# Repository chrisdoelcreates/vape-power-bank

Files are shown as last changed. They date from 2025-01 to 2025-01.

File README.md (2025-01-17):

# Disposable Vape Powerbank Project

This repository contains everything you need to build a functional 100W power bank using lithium-ion cells salvaged from disposable vapes.

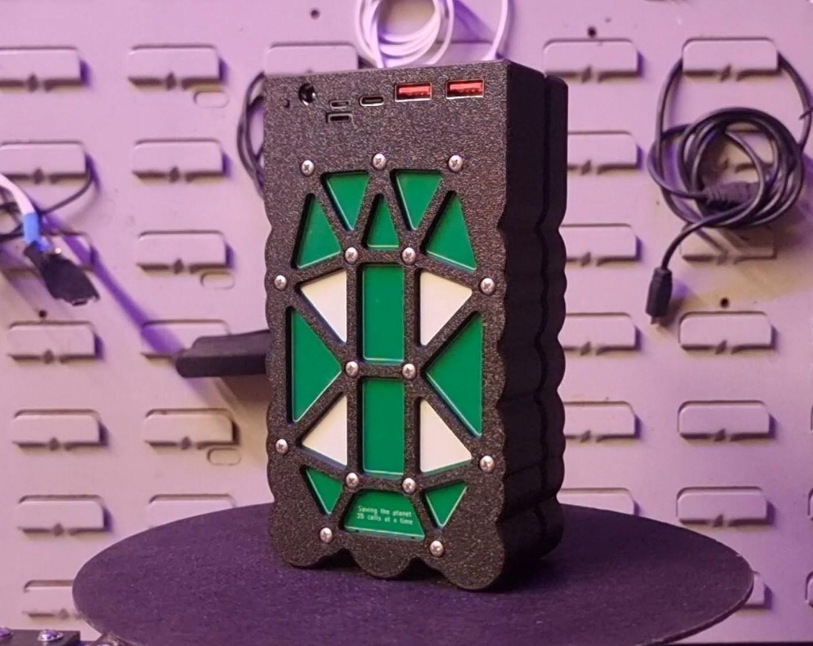
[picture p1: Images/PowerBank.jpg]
Finished Power Bank


## 📺 Watch the Video

See the entire build process in action on my YouTube channel:

[Watch on YouTube](https://youtu.be/kMiJdfgIfqI)

---

This powerbank is an upgrade from my [initial design](https://www.youtube.com/watch?v=ehp23hrrEHY) and is now smaller, lighter, safer, and easier to assemble.
It’s a fantastic way to repurpose vape batteries and contribute to reducing e-waste while learning valuable electronics and 3D printing skills.

---

## ⚠️ Disclaimer

This project involves handling lithium-ion batteries, which can be dangerous if mishandled. By using these designs or instructions, you acknowledge and agree to the following:

- You assume all risks associated with the assembly and use of this project.
- This project is provided "as-is," with no guarantees of safety or performance.
- Always take appropriate safety precautions and seek professional guidance if unsure.

Please read the full [Disclaimer](DISCLAIMER.md) before proceeding.

---

## Affiliate Links & Sponsorship Disclosure

This repository contains affiliate links to suppliers and services. If you use these links to purchase parts (from Aliexpress) or sign up for services (such as JLCPCB), I may earn a small commission at no extra cost to you. These links help support the development of this project and my YouTube channel.

Thank you for supporting my work!

---

## 🚀 Project Overview

In this project, you will:
- Extract lithium-ion cells from disposable vapes.
- Test and prepare the cells for use.
- Assemble a 3D-printed cell holder and enclosure.
- Install custom PCBs to balance charge the cells and wire them up to form a 5S7P (5 cells in series, 7 cells in parallel) battery pack.
- Wire up a fast-charge USB powerbank board.

### Key Features:
- Doesn't require directly soldering the cells together.
- Multifunction PCBs (balance charging and power delivery) to reduce parts cost.
- Open-source PCBs & 3D prints for easy customization and collaboration.
- Supports 100W USB C PD charging.
---

## 📂 Repository Contents

This repository is organized as follows:
```
Disposable-Vape-Powerbank/
├── README.md           # Introduction and instructions
├── DISCLAIMER.md       # Full project disclaimer
├── LICENSE             # Project licensing details
├── PCB-Files/          # PCB related files
│   ├── Production-Files/   # PCB files for ordering
│   ├── Schematic.pdf       # PCB schematic
│   └── KiCad_Project/      # KiCAD project files
├── 3D-Models/          # Fusion360 files and links to printables
└── Images/             # Photos and renders of the project
```
## 🛠️ Quick Start Guide

Follow these steps to build your own disposable vape power bank:

1. *Download Files*
   - Click the green *Code* button and select *Download ZIP*. Then extract the repository files.
   - or clone the repository:
     git clone [https://github.com/username/Disposable-Vape-Powerbank.git](https://github.com/chrisdoelcreates/vape-power-bank)
     
2. *Order the PCBs*
    - Head over to [JLCPCB](https://jlcpcb.com/?from=cdd) (or any other PCB ordering site)
    - Sign up/Log in
    - Head to the order page
    - Upload the Gerber file from Disposable-Vape-Powerbank/PCB-Files/Production-Files/
    - Refer to 10:13 in the [project video](https://youtu.be/h3FRk3OD1Ug) for order settings
    - Ensure 'Assembly' is checked
    - Upload the CPL and BOM files
    - Rotate the connectors to match the orientation within the video
    - Place the order!
  *If you get an email asking if the polarities of the springs are correct - reply that they are*

3. *Order the USB board*
    - [USB board - Type 1 (Recommended - Used in the video)](https://s.click.aliexpress.com/e/_oBGOqhR)
       - *ENSURE THE 5S OPTION IS SELECTED*
    - [USB board - Type 2 (More USB C ports - requires different 3D prints to the video)](https://s.click.aliexpress.com/e/_oBXyxIH)
       - *ENSURE THE 5S OPTION IS SELECTED*

4. *Order the conductive tape*
    - [Conductive tape](https://s.click.aliexpress.com/e/_olaCL05)
       - *ENSURE the '10mm' & 'Conductive on both sides' options are selected*

5. *Order optional extras*
    - [Right angle JST connector](https://s.click.aliexpress.com/e/_oEeP6lf)
      - *ENSURE XH2.54MM, Length 10CM, 4P IS SELECTED*
      - Not essential but makes wiring the board slightly easier
    - [8 Channel Cell Tester](https://s.click.aliexpress.com/e/_oEuMn9T)
      - Also not essential
      - Allows you to match the battery capacities for each parallel row - improves powerbank battery life & lifespan
      - Good if you regularly do battery related projects

6. *Print the parts*
    - Easiest: Find the right size on [printables](https://www.printables.com/@montecha_2397581/collections/2035794)
      Or
    - Download the cell holder from the 3D models folder
    - Download the enclosure from the 3D models folder
      - Select the enclosure depending on your board type
    - Print out the parts!

7. *Build the Powerbank!*
     - Follow along with the Youtube video

---

## 🧾 Licensing

This project is licensed under the [MIT License](LICENSE). You are free to use, modify, and distribute the files, provided you include proper attribution and accept the project’s disclaimers.

---

## 🤝 Contributions

Contributions are welcome! If you have suggestions, improvements, or issues, feel free to:
- Open an issue in this repository.
- Submit a pull request with your changes.

---

## 🌟 Acknowledgments

A big thank you to:
- *JLCPCB* for sponsoring the youtube video/project.
- Everyone who has supported and engaged with my Youtube channel.

---

Enjoy building your power bank and contributing to e-waste reduction!

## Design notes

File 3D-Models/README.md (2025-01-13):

# 3D Model Files

This directory contains 3D model files to print the enclosures and cell holders for the disposable vape power bank project. The models are organized by USB board type and compatible cell lengths to make it easy to find the appropriate files for your build.

If your cells are not 30mm, 35mm or 40mm in length, you can modify the cell holder and enclosure .step models to fit your particular cell size.

**NOTE:** This project only supports vape cells of 13mm diameter. 

## Overview
The project supports **two USB board types** and **three common cell lengths**:

### USB Board Types
1. [**Type 1 (Recommended)**](https://s.click.aliexpress.com/e/_oBGOqhR)
   - This is the primary USB board featured in the project video.
   - It is recommended for most users.
2. [**Type 2**](https://s.click.aliexpress.com/e/_oBXyxIH)
   - Features a larger screen and more USB ports.
   - Requires slightly different 3D printed parts due to the board's size and layout.

### Cell Lengths
The models are optimized for the following common cell lengths:
- **30mm cells**: Typically referred to as 13300 cells.
- **35mm cells**: Typically referred to as 13350 cells.
- **40mm cells**: Typically referred to as 13400 cells.

Each folder contains the necessary 3D models to build the enclosure and cell holder for the specified cell length.

---

## Directory Structure

The file structure is organized as follows:

```
├───USB Board Type 1
│   ├───30mm_cell
│   │   ├───Step
│   │   └───STL
│   ├───35mm_cell
│   │   ├───Step
│   │   └───STL
│   └───40mm_cell
│       ├───Step
│       └───STL
└───USB Board Type 2
    ├───30mm_cell
    │   ├───Step
    │   └───STL
    ├───35mm_cell
    │   ├───Step
    │   └───STL
    └───40mm_cell
        ├───Step
        └───STL
```

### Folders and File Types
- **Step Folder**: Contains `.step` files for the parts required for each different cell type, which can be used in CAD software for further modifications.
- **STL Folder**: Contains `.3mf` files optimized for 3D printing.
  - Includes parts like:
    - `cell_holder`
    - `enclosure_bottom`
    - `enclosure_top`
    - (for Type 2) `enclosure_top_tab`

---

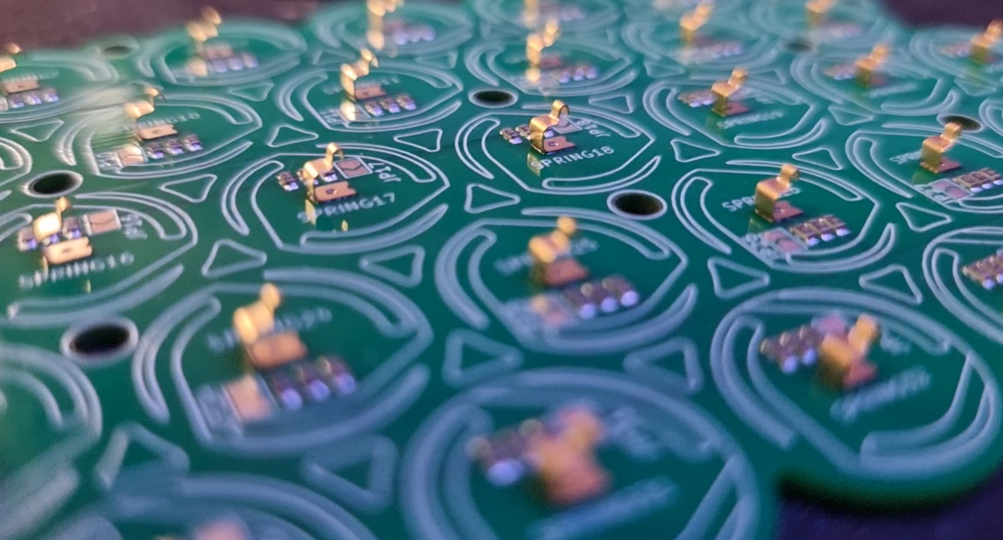
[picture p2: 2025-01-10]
Images/PCB_close_up.jpg

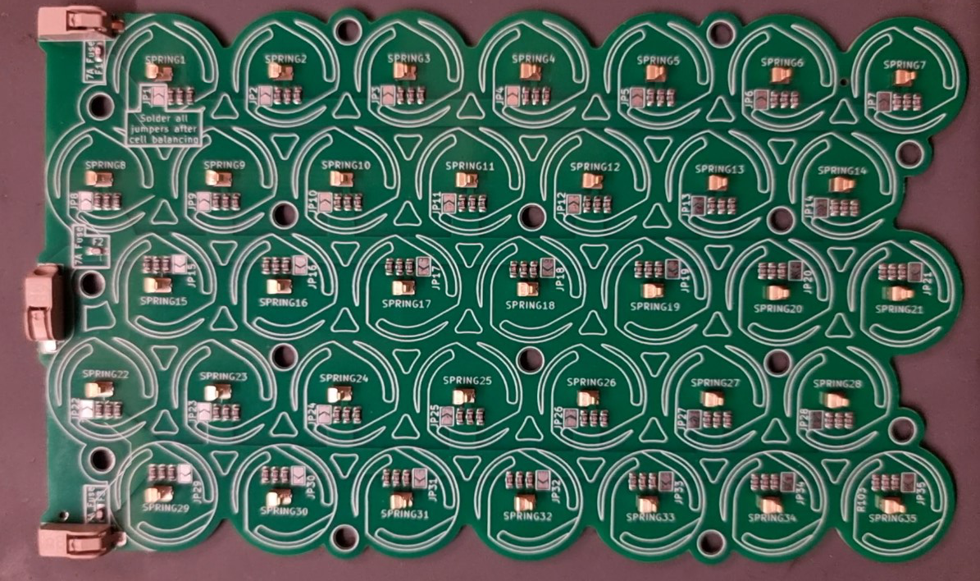
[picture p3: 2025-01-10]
Images/PCB.jpg

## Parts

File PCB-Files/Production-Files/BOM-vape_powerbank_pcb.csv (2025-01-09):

Comment | Designator | Footprint | LCSC
R | R1,R10,R100,R101,R102,R103,R104,R105,R11,R12,R13,R14,R15,R16,R17,R18,R19,R2,R20,R21,R22,R23,R24,R25,R26,R27,R28,R29,R3,R30,R31,R32,R33,R34,R35,R36,R37,R38,R39,R4,R40,R41,R42,R43,R44,R45,R46,R47,R48,R49,R5,R50,R51,R52,R53,R54,R55,R56,R57,R58,R59,R6,R60,R61,R62,R63,R64,R65,R66,R67,R68,R69,R7,R70,R71,R72,R73,R74,R75,R76,R77,R78,R79,R8,R80,R81,R82,R83,R84,R85,R86,R87,R88,R89,R9,R90,R91,R92,R93,R94,R95,R96,R97,R98,R99 | R_0603_1608Metric | C23164
spring_tab | SPRING1,SPRING10,SPRING11,SPRING12,SPRING13,SPRING14,SPRING15,SPRING16,SPRING17,SPRING18,SPRING19,SPRING2,SPRING20,SPRING21,SPRING22,SPRING23,SPRING24,SPRING25,SPRING26,SPRING27,SPRING28,SPRING29,SPRING3,SPRING30,SPRING31,SPRING32,SPRING33,SPRING34,SPRING35,SPRING4,SPRING5,SPRING6,SPRING7,SPRING8,SPRING9 | spring_tab | C2826543
Fuse | F1,F2,F3 | Fuse_0603_1608Metric_Pad1.05x0.95mm_HandSolder | C310953
Conn_01x01_Pin | J1,J2,J3 | SMD_spring_clamp_connector_1x1 | C5197183

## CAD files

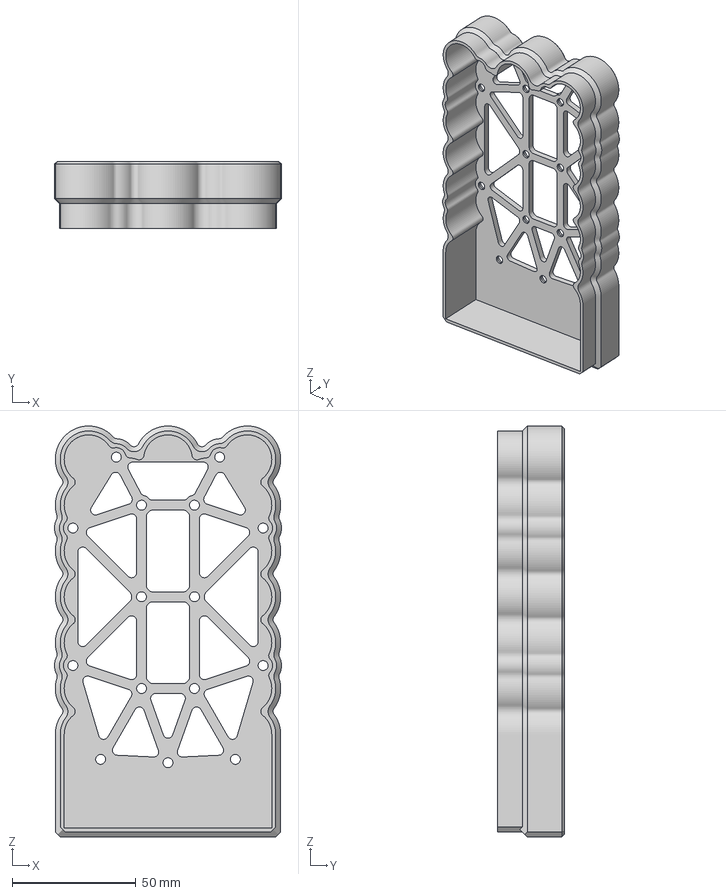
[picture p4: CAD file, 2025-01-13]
3D-Models/USB Board Type 1/30mm_cell/STL/Mk4 PCB 1 N&B 31mm Base Protector.3mf
91.6 x 27.0 x 165.9 mm

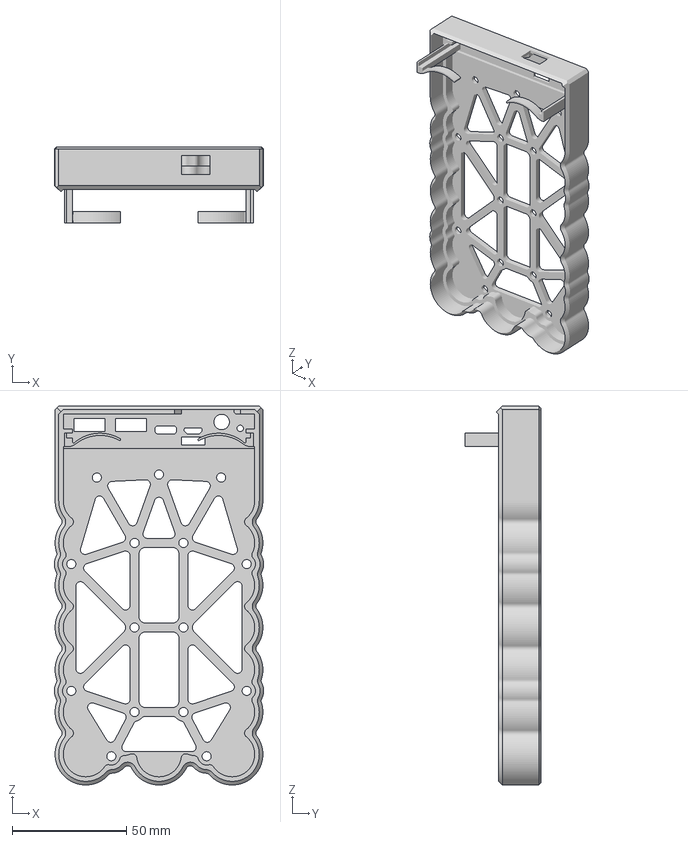
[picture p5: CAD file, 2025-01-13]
3D-Models/USB Board Type 1/35mm_cell/STL/Mk4 PCB 1 N&B 36mm Top Protector.3mf
91.6 x 33.4 x 165.9 mm

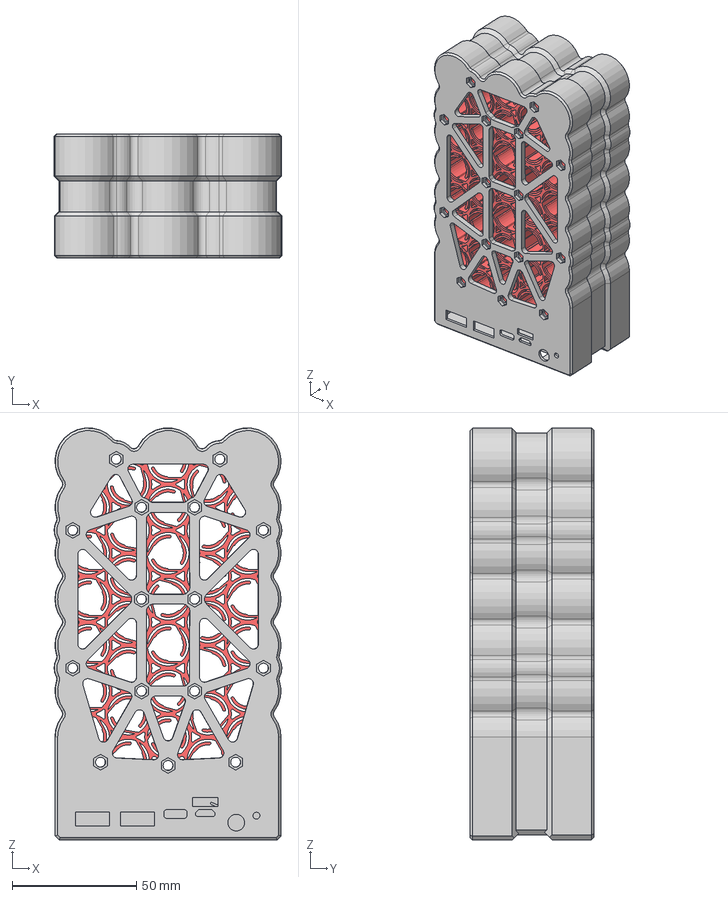
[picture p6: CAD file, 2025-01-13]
3D-Models/USB Board Type 1/40mm_cell/Step/40mm_cell_prints.step
91.8 x 50.0 x 165.9 mm
Base protector
Top protector
41mm cell holder

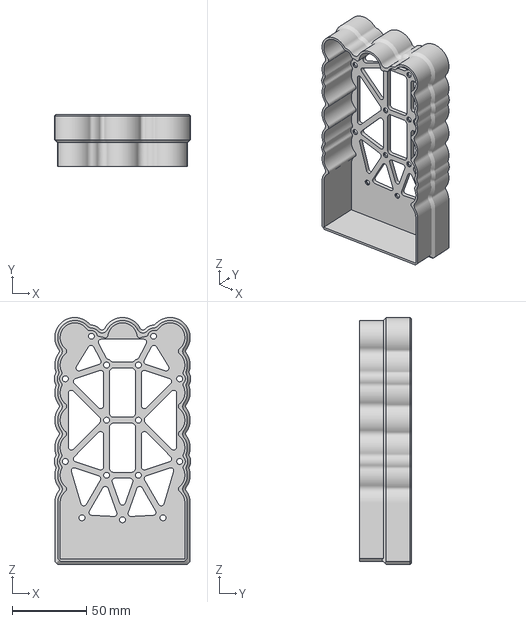
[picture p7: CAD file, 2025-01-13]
3D-Models/USB Board Type 1/40mm_cell/STL/enclosure_bottom.3mf
91.6 x 35.0 x 165.9 mm

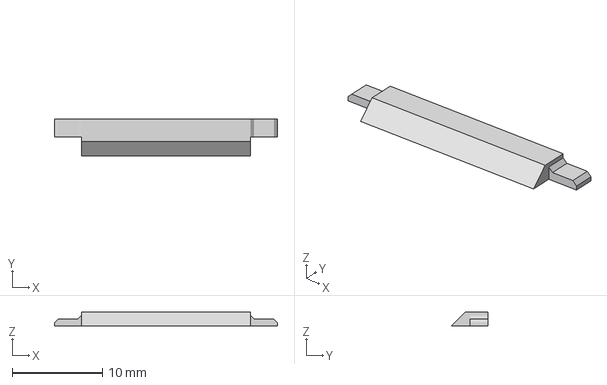
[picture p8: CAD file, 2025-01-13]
3D-Models/USB Board Type 2/30mm_cell/STL/enclosure_top_tab.3mf
24.7 x 4.10 x 1.60 mm

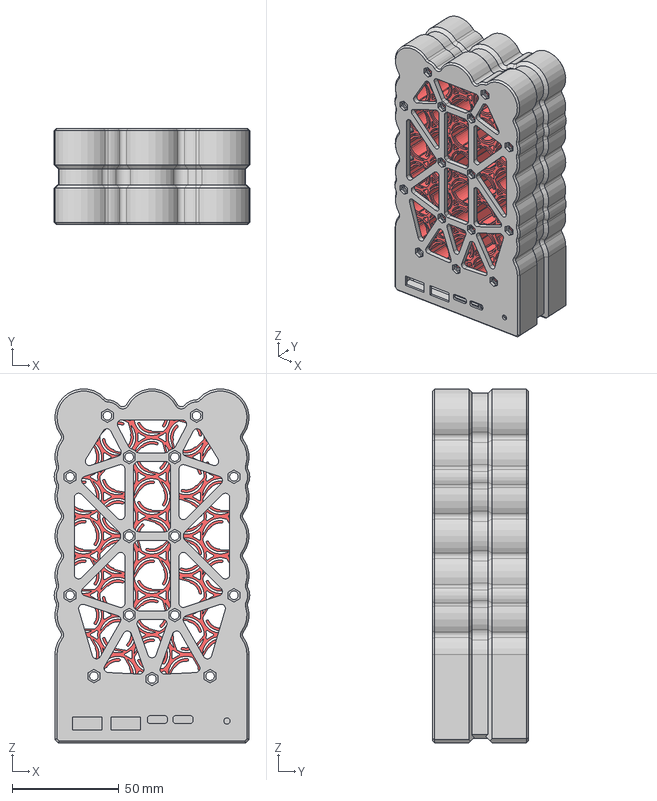
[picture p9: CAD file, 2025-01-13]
3D-Models/USB Board Type 2/35mm_cell/Step/35mm_cell_prints.step
91.6 x 45.0 x 165.8 mm
Base protector
Top protector
Cell Holder Mk2

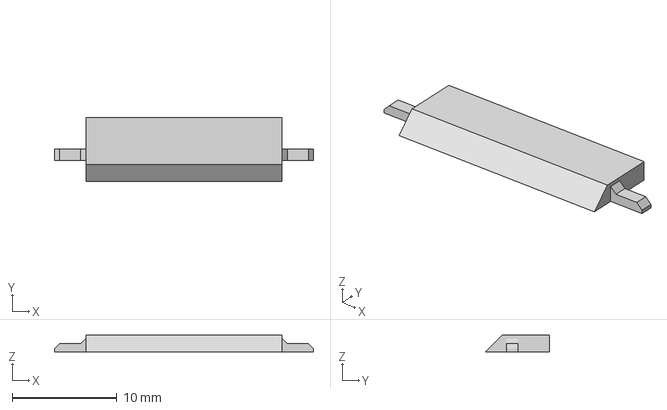
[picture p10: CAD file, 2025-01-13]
3D-Models/USB Board Type 2/40mm_cell/STL/enclosure_top_tab.3mf
24.7 x 6.10 x 1.60 mm

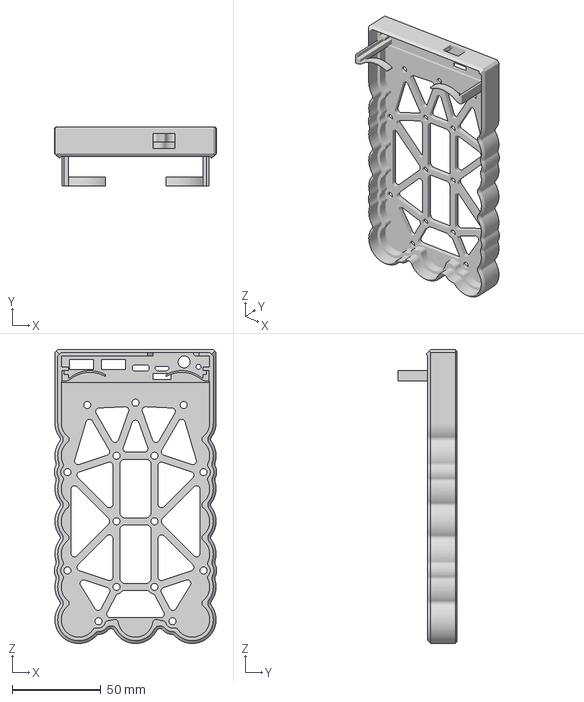
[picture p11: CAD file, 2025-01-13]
3D-Models/USB Board Type 1/30mm_cell/STL/Mk4 PCB 1 N&B 31mm Top Protector .3mf
91.6 x 33.4 x 165.9 mm

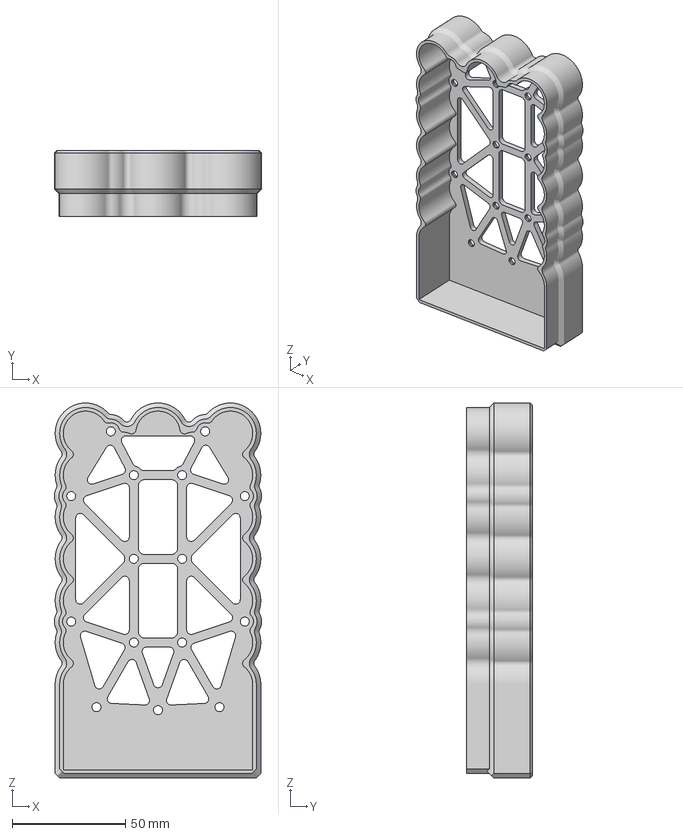
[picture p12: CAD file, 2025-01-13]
3D-Models/USB Board Type 1/35mm_cell/STL/Mk4 PCB 1 N&B 36mm Base Protector.3mf
91.6 x 29.0 x 165.9 mm

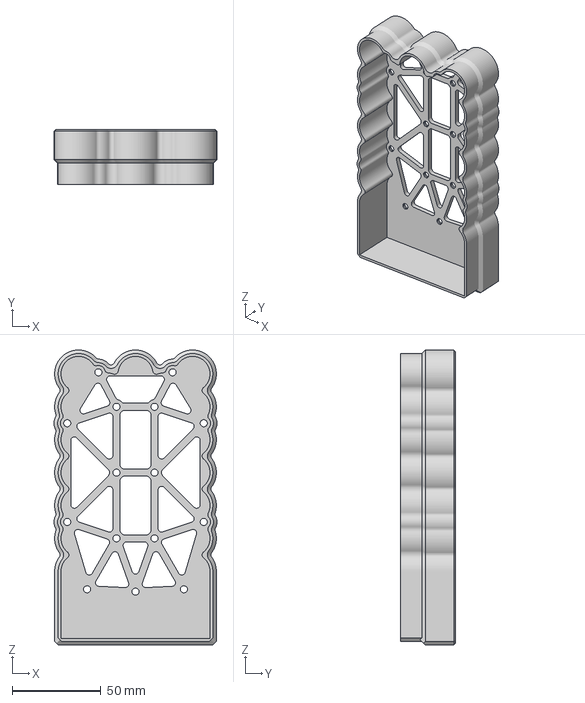
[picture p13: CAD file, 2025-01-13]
3D-Models/USB Board Type 2/35mm_cell/STL/enclosure_bottom.3mf
91.6 x 31.0 x 165.9 mm

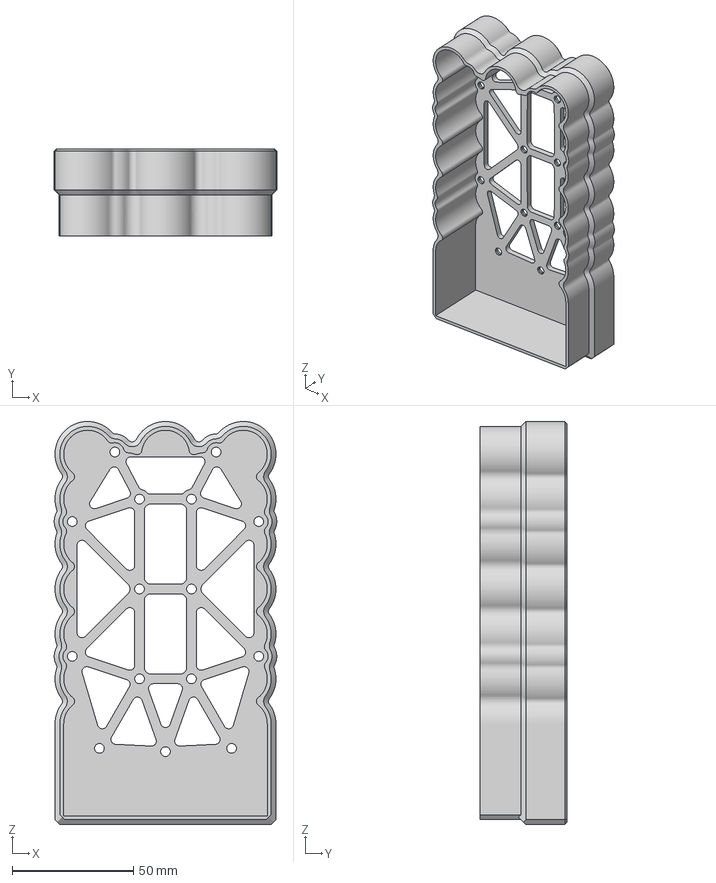
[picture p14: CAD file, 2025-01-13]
3D-Models/USB Board Type 2/40mm_cell/STL/enclosure_bottom.3mf
91.6 x 36.0 x 165.9 mm

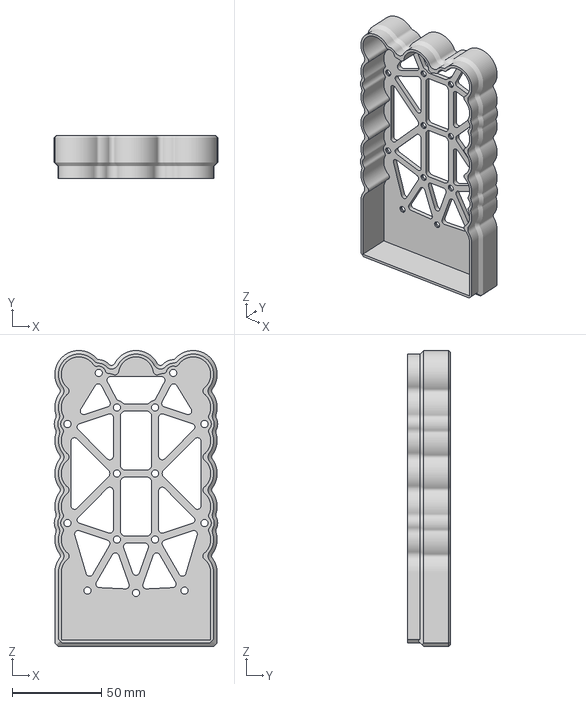
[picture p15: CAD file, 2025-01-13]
3D-Models/USB Board Type 2/30mm_cell/STL/enclosure_bottom.3mf
91.6 x 24.0 x 165.9 mm

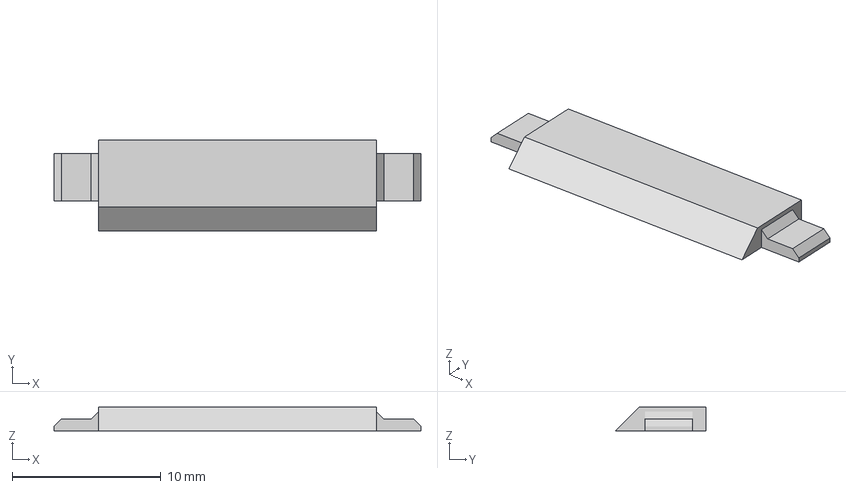
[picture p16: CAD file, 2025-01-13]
3D-Models/USB Board Type 2/35mm_cell/STL/enclosure_top_tab.3mf
24.7 x 6.10 x 1.60 mm

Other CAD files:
3D-Models/USB Board Type 2/35mm_cell/STL/enclosure_top.3mf
3D-Models/USB Board Type 1/40mm_cell/STL/enclosure_top.3mf
3D-Models/USB Board Type 2/30mm_cell/STL/enclosure_top.3mf
3D-Models/USB Board Type 2/40mm_cell/STL/enclosure_top.3mf

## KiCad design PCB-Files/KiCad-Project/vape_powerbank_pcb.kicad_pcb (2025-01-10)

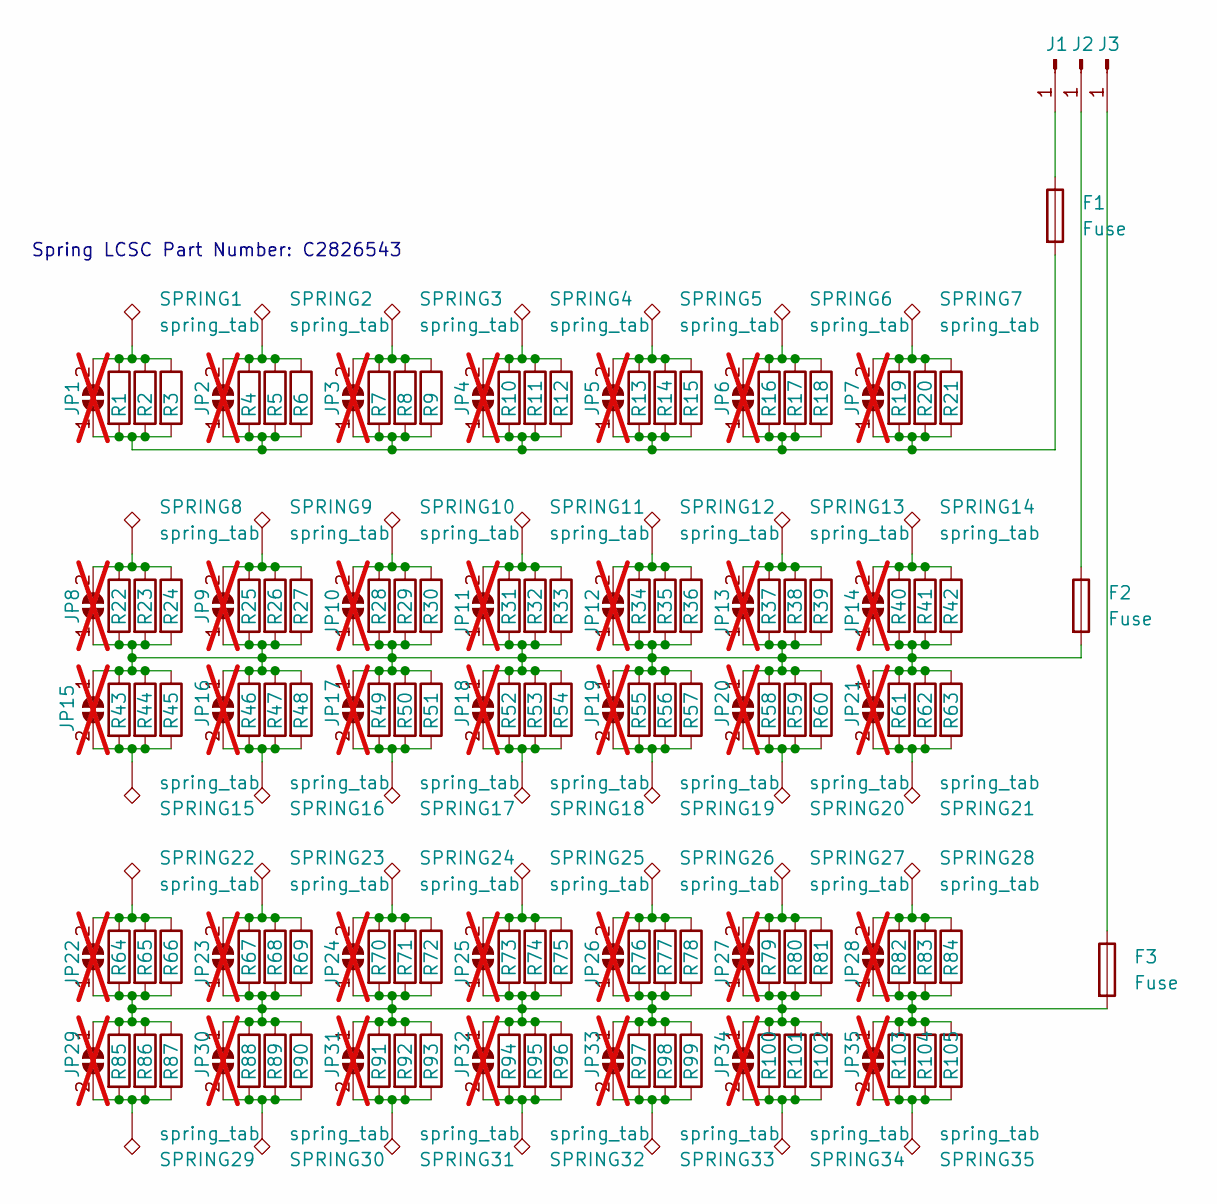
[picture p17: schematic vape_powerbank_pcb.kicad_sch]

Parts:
F1, F2, F3: Fuse; Fuse_0603_1608Metric_Pad1.05x0.95mm_HandSolder
J1, J2, J3: Conn_01x01_Pin; SMD_spring_clamp_connector_1x1
JP1, JP2, JP3, JP4, JP5, JP6, JP7, JP8, JP9, JP10, JP11, JP12, JP13, JP14, JP15, JP16, JP17, JP18, JP19, JP20, JP21, JP22, JP23, JP24, JP25, JP26, JP27, JP28, JP29, JP30, JP31, JP32, JP33, JP34, JP35: SolderJumper_2_Open; SolderJumper-2_P1.3mm_Open_TrianglePad1.0x1.5mm; not fitted
R1, R2, R3, R4, R5, R6, R7, R8, R9, R10, R11, R12, R13, R14, R15, R16, R17, R18, R19, R20, R21, R22, R23, R24, R25, R26, R27, R28, R29, R30, R31, R32, R33, R34, R35, R36, R37, R38, R39, R40, R41, R42, R43, R44, R45, R46, R47, R48, R49, R50, R51, R52, R53, R54, R55, R56, R57, R58, R59, R60, R61, R62, R63, R64, R65, R66, R67, R68, R69, R70, R71, R72, R73, R74, R75, R76, R77, R78, R79, R80, R81, R82, R83, R84, R85, R86, R87, R88, R89, R90, R91, R92, R93, R94, R95, R96, R97, R98, R99, R100, R101, R102, R103, R104, R105: R; R_0603_1608Metric
SPRING1, SPRING2, SPRING3, SPRING4, SPRING5, SPRING6, SPRING7, SPRING8, SPRING9, SPRING10, SPRING11, SPRING12, SPRING13, SPRING14, SPRING15, SPRING16, SPRING17, SPRING18, SPRING19, SPRING20, SPRING21, SPRING22, SPRING23, SPRING24, SPRING25, SPRING26, SPRING27, SPRING28, SPRING29, SPRING30, SPRING31, SPRING32, SPRING33, SPRING34, SPRING35: spring_tab

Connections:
unnamed: F1.1, J1.1
unnamed: F2.1, J2.1
unnamed: F3.1, J3.1
unnamed: F1.2, JP1.1 (A), JP2.1 (A), JP3.1 (A), JP4.1 (A), JP5.1 (A), JP6.1 (A), JP7.1 (A), R1.2, R2.2, R3.2, R4.2, R5.2, R6.2, R7.2, R8.2, R9.2, R10.2, R11.2, R12.2, R13.2, R14.2, R15.2, R16.2, R17.2, R18.2, R19.2, R20.2, R21.2
unnamed: JP1.2 (B), R1.1, R2.1, R3.1, SPRING1.1
unnamed: JP2.2 (B), R4.1, R5.1, R6.1, SPRING2.1
unnamed: JP3.2 (B), R7.1, R8.1, R9.1, SPRING3.1
unnamed: JP4.2 (B), R10.1, R11.1, R12.1, SPRING4.1
unnamed: JP5.2 (B), R13.1, R14.1, R15.1, SPRING5.1
unnamed: JP6.2 (B), R16.1, R17.1, R18.1, SPRING6.1
unnamed: JP7.2 (B), R19.1, R20.1, R21.1, SPRING7.1
unnamed: JP8.2 (B), R22.1, R23.1, R24.1, SPRING8.1
unnamed: JP9.2 (B), R25.1, R26.1, R27.1, SPRING9.1
unnamed: F2.2, JP8.1 (A), JP9.1 (A), JP10.1 (A), JP11.1 (A), JP12.1 (A), JP13.1 (A), JP14.1 (A), JP15.1 (A), JP16.1 (A), JP17.1 (A), JP18.1 (A), JP19.1 (A), JP20.1 (A), JP21.1 (A), R22.2, R23.2, R24.2, R25.2, R26.2, R27.2, R28.2, R29.2, R30.2, R31.2, R32.2, R33.2, R34.2, R35.2, R36.2, R37.2, R38.2, R39.2, R40.2, R41.2, R42.2, R43.1, R44.1, R45.1, R46.1, R47.1, R48.1, R49.1, R50.1, R51.1, R52.1, R53.1, R54.1, R55.1, R56.1, R57.1, R58.1, R59.1, R60.1, R61.1, R62.1, R63.1
unnamed: JP10.2 (B), R28.1, R29.1, R30.1, SPRING10.1
unnamed: JP11.2 (B), R31.1, R32.1, R33.1, SPRING11.1
unnamed: JP12.2 (B), R34.1, R35.1, R36.1, SPRING12.1
unnamed: JP13.2 (B), R37.1, R38.1, R39.1, SPRING13.1
unnamed: JP14.2 (B), R40.1, R41.1, R42.1, SPRING14.1
unnamed: JP15.2 (B), R43.2, R44.2, R45.2, SPRING15.1
unnamed: JP16.2 (B), R46.2, R47.2, R48.2, SPRING16.1
unnamed: JP17.2 (B), R49.2, R50.2, R51.2, SPRING17.1
unnamed: JP18.2 (B), R52.2, R53.2, R54.2, SPRING18.1
unnamed: JP19.2 (B), R55.2, R56.2, R57.2, SPRING19.1
unnamed: JP20.2 (B), R58.2, R59.2, R60.2, SPRING20.1
unnamed: JP21.2 (B), R61.2, R62.2, R63.2, SPRING21.1
unnamed: F3.2, JP22.1 (A), JP23.1 (A), JP24.1 (A), JP25.1 (A), JP26.1 (A), JP27.1 (A), JP28.1 (A), JP29.1 (A), JP30.1 (A), JP31.1 (A), JP32.1 (A), JP33.1 (A), JP34.1 (A), JP35.1 (A), R64.2, R65.2, R66.2, R67.2, R68.2, R69.2, R70.2, R71.2, R72.2, R73.2, R74.2, R75.2, R76.2, R77.2, R78.2, R79.2, R80.2, R81.2, R82.2, R83.2, R84.2, R85.1, R86.1, R87.1, R88.1, R89.1, R90.1, R91.1, R92.1, R93.1, R94.1, R95.1, R96.1, R97.1, R98.1, R99.1, R100.1, R101.1, R102.1, R103.1, R104.1, R105.1
unnamed: JP22.2 (B), R64.1, R65.1, R66.1, SPRING22.1
unnamed: JP23.2 (B), R67.1, R68.1, R69.1, SPRING23.1
unnamed: JP24.2 (B), R70.1, R71.1, R72.1, SPRING24.1
unnamed: JP25.2 (B), R73.1, R74.1, R75.1, SPRING25.1
unnamed: JP26.2 (B), R76.1, R77.1, R78.1, SPRING26.1
unnamed: JP27.2 (B), R79.1, R80.1, R81.1, SPRING27.1
unnamed: JP28.2 (B), R82.1, R83.1, R84.1, SPRING28.1
unnamed: JP29.2 (B), R85.2, R86.2, R87.2, SPRING29.1
unnamed: JP30.2 (B), R88.2, R89.2, R90.2, SPRING30.1
unnamed: JP31.2 (B), R91.2, R92.2, R93.2, SPRING31.1
unnamed: JP32.2 (B), R94.2, R95.2, R96.2, SPRING32.1
unnamed: JP33.2 (B), R97.2, R98.2, R99.2, SPRING33.1
unnamed: JP34.2 (B), R100.2, R101.2, R102.2, SPRING34.1
unnamed: JP35.2 (B), R103.2, R104.2, R105.2, SPRING35.1

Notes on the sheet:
Spring LCSC Part Number: C2826543

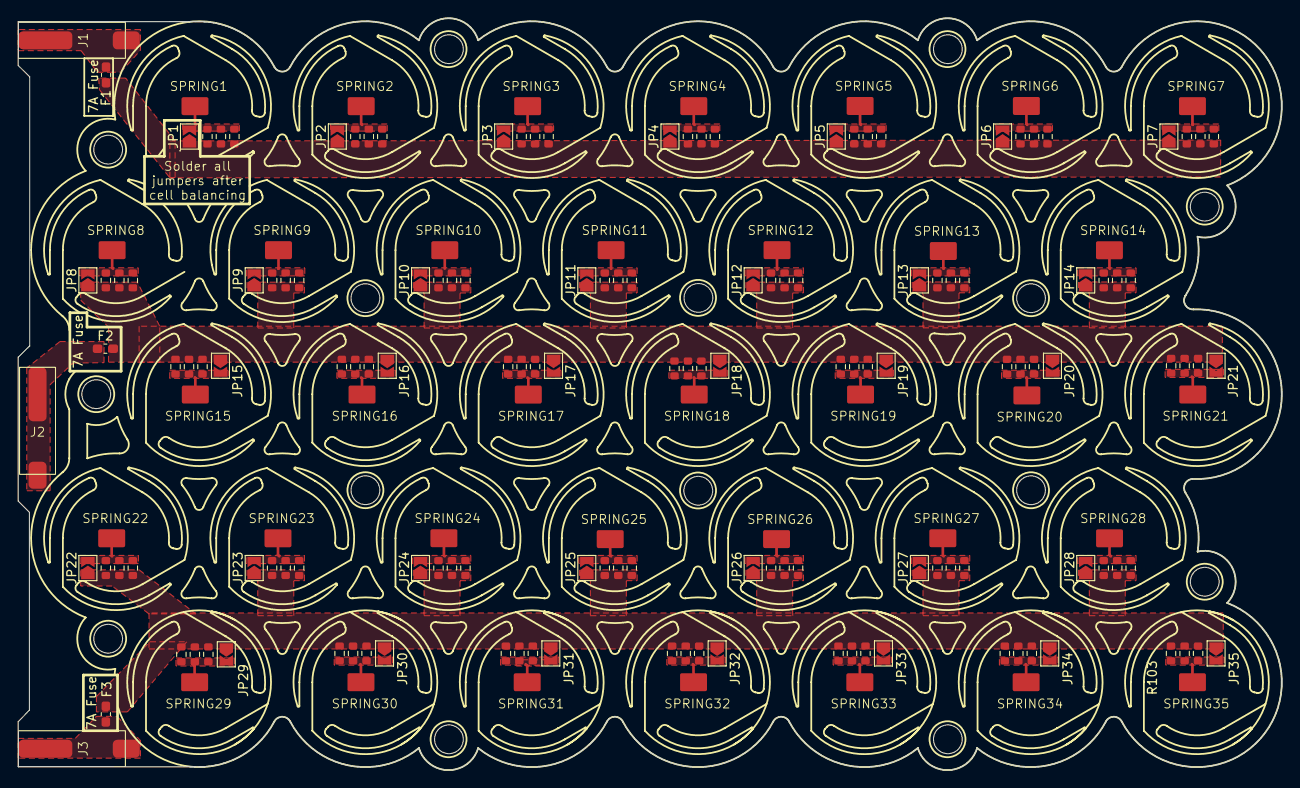
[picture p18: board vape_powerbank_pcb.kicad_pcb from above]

Board: 2 copper layers, 140.6 x 83.6 mm, 181 parts (0 on the bottom side), 41 nets.

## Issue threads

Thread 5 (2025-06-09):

schematic

qingshanzimu, 2025-06-09:
The schematic is missing

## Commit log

2025-01-09 Added kicad project & repo file structure
    [BOM.csv, vape_powerbank_pcb.kicad_pcb, vape_powerbank_pcb.kicad_sch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]
2025-01-10 Reduced fusable trace width to 0.3mm (~12A fusing current) and added images
    [BOM-vape_powerbank_pcb.csv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]
2025-01-13 added 3D model files
    [35mm_cell_prints.step, 40mm_cell_prints.step, Mk4 PCB 1 N&B 31mm Base Protector.3mf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]
2025-01-17 Added conductive tape to BOM
2025-01-17 Added printables link
2025-01-18 Fix CPL so manual rotation of J1, J2, and J3 is no longer needed.
    Fix CPL so manual rotation of J1, J2, and J3 is no longer needed.
    [CPL-vape_powerbank_pcb.csv]
2025-01-18 Update positions to be more consistant to the official part
    positions updated to more closely match
    https://www.lcsc.com/product-detail/Spring-Clamp-System-Terminal-Block_HDGC-HDGC4001SMD-S-1P_C5197183.html
    https://www.lcsc.com/datasheet/lcsc_datasheet_2410121457_HDGC-HDGC4001SMD-S-1P_C5197183.pdf
    [CPL-vape_powerbank_pcb.csv]
